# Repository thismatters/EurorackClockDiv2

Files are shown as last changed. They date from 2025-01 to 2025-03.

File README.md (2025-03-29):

# Clock Divider (type 2)

```
      ----  ----  ----  ----  ----  ----  ----  ----  ----
IN    |  |  |  |  |  |  |  |  |  |  |  |  |  |  |  |  |  |
    ---  ----  ----  ----  ----  ----  ----  ----  ----  ---
      ----              ----              ----
OUT   |  |              |  |              |  |
n=3 ---  ----------------  ----------------  ---------------
```

This clock divider takes a regular clock signal and generates one pulse every `n` input steps. A knob allows you choose `n` between 1 and 10. Combine this with the [binary clock divider](https://www.github.com/thismatters/EurorackClockDiv/) in my series to generate many permutations on a clock signal.

The circuit here is based on the [Yusynth Clock Divider](https://yusynth.net/Modular/EN/DIVIDER/index.html) with minor tweaks to make it more Eurorack friendly. The changes I've made are thus:
* Selected resistors appropriate for +/-12V rails,
* Added polarity protection so that a backward power header doesn't fry anything (twin series schotty diodes: BAT54SL),
* Full surface mount design,
* More step options!

The Yusynth page is a treasure trove of information about this circuit that I am too amateur to claim as my own; please read that outstanding page before using this circuit. The page provides many details and other implementations of this circuit that you may find suitable.

The KiCAD project here uses the library/footprints [found in my companion repo](https://github.com/thismatters/EurorackKiCAD).

## Width

10hp on a 1u rack (Intellijel).

## Inputs

Jacks:
- Clock input*
- Reset gate

Knobs:
- 10 position switch for choosing the frequency of gate outputs

\* Note that this module requires a fairly clean input clock signal.

## Outputs

Gate output. LED indicator.

## Vendors

There are part numbers in the [BOM](clkdiv2.csv) for many of the parts (not for basic passives though) at the following vendors:

* [Mouser](https://www.mouser.com): Needs no introduction. Get your ICs from here (or [digikey](https://www.digikey.com)).
* [Tayda Electronics](https://www.taydaelectronics.com/): Good supplier for passive components; audio jacks, and potentiometers. Their audio jacks are slightly smaller than the thonkiconn from thonk.
* [Love My Switches](https://lovemyswitches.com/): Has [really good knobs](https://lovemyswitches.com/anodized-aluminum-knob-the-lo-fi-1-4-smooth-shaft-12-5mm-od/) to go on those potentiometers!
* [OSHPark](https://oshpark.com/): Fast and (relatively) cheap PCB manufacturer. [V0a works great!](https://oshpark.com/shared_projects/LyyWQIPF)

## Changelog

### V0a (Same solder paste stencil as V0 will work here)
- [x] Fixed wrong schematic symbol for dual transistor package (Q3 pinout didn't match the BCM847.)
- [x] Fixed LED footprint to correct side of the board
- [x] Fixed D9 screenprint overlap

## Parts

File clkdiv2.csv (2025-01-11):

# | Reference | Qty | Value | Footprint | DNP | Vendor | PartNum
1 | C1, C2 | 2 | 22u 50V | Capacitor_THT:CP_Radial_D5.0mm_P2.50mm
2 | C3 | 1 | 100n | Capacitor_SMD:C_0805_2012Metric
3 | C4 | 1 | 47n box | Capacitor_THT:C_Rect_L7.2mm_W2.5mm_P5.00mm_FKS2_FKP2_MKS2_MKP2
4 | D1, D2 | 2 | BAT54S | Package_TO_SOT_SMD:SOT-23 |  | Mouser | 863-BAT54SLT1G
5 | D3, D4, D5, D6, D7, D8 | 6 | 1N4148 | Diode_SMD:D_SOD-323_HandSoldering
6 | D9 | 1 | Zener 5.1V | Diode_SMD:D_MiniMELF
7 | D10 | 1 | LED_GREEN | LED_THT:LED_D3.0mm
8 | J1 | 1 | Conn_02x05_Odd_Even | Eurorack:PinHeader_2x05_P2.54mm_Vertical |  | Tayda | A-2939
9 | J2, J3, J4 | 3 | AudioJack2_SwitchT | Eurorack:AudioJack2_Tayda_A-2566 |  | Tayda | A-2566
10 | J5, J7, J9 | 3 | Conn_01x03_Socket | Connector_PinSocket_2.54mm:PinSocket_1x03_P2.54mm_Vertical
11 | J6, J8, J10 | 3 | Conn_01x03_Pin | Connector_PinHeader_2.54mm:PinHeader_1x03_P2.54mm_Vertical
12 | Q1, Q2, Q3 | 3 | BCM847 | Package_SO:TSOP-6_1.65x3.05mm_P0.95mm |  | Mouser | 771-BCM847DS135
13 | R1, R2, R20 | 3 | 10 | Resistor_SMD:R_0805_2012Metric
14 | R3, R9 | 2 | 1M | Resistor_SMD:R_0805_2012Metric
15 | R4 | 1 | 1.2M | Resistor_SMD:R_0805_2012Metric
16 | R5, R6, R12, R14 | 4 | 22K | Resistor_SMD:R_0805_2012Metric
17 | R7 | 1 | 220 | Resistor_SMD:R_0805_2012Metric
18 | R8 | 1 | 100K | Resistor_SMD:R_0805_2012Metric
19 | R10 | 1 | 10K | Resistor_SMD:R_0805_2012Metric
20 | R11, R16 | 2 | 220K | Resistor_SMD:R_0805_2012Metric
21 | R13, R18, R19 | 3 | 1K | Resistor_SMD:R_0805_2012Metric
22 | R15 | 1 | 4.7K | Resistor_SMD:R_0805_2012Metric
23 | R17 | 1 | 120K | Resistor_SMD:R_0805_2012Metric
24 | SW1 | 1 | SW_Rotary12 | Eurorack:Switch_Rotary_NKK_MRK_112 |  | Mouser | 633-MRK112-BA
25 | U1 | 1 | 4017 | Package_SO:TSSOP-16_4.4x5mm_P0.65mm |  | Mouser | 595-CD4017BPWR

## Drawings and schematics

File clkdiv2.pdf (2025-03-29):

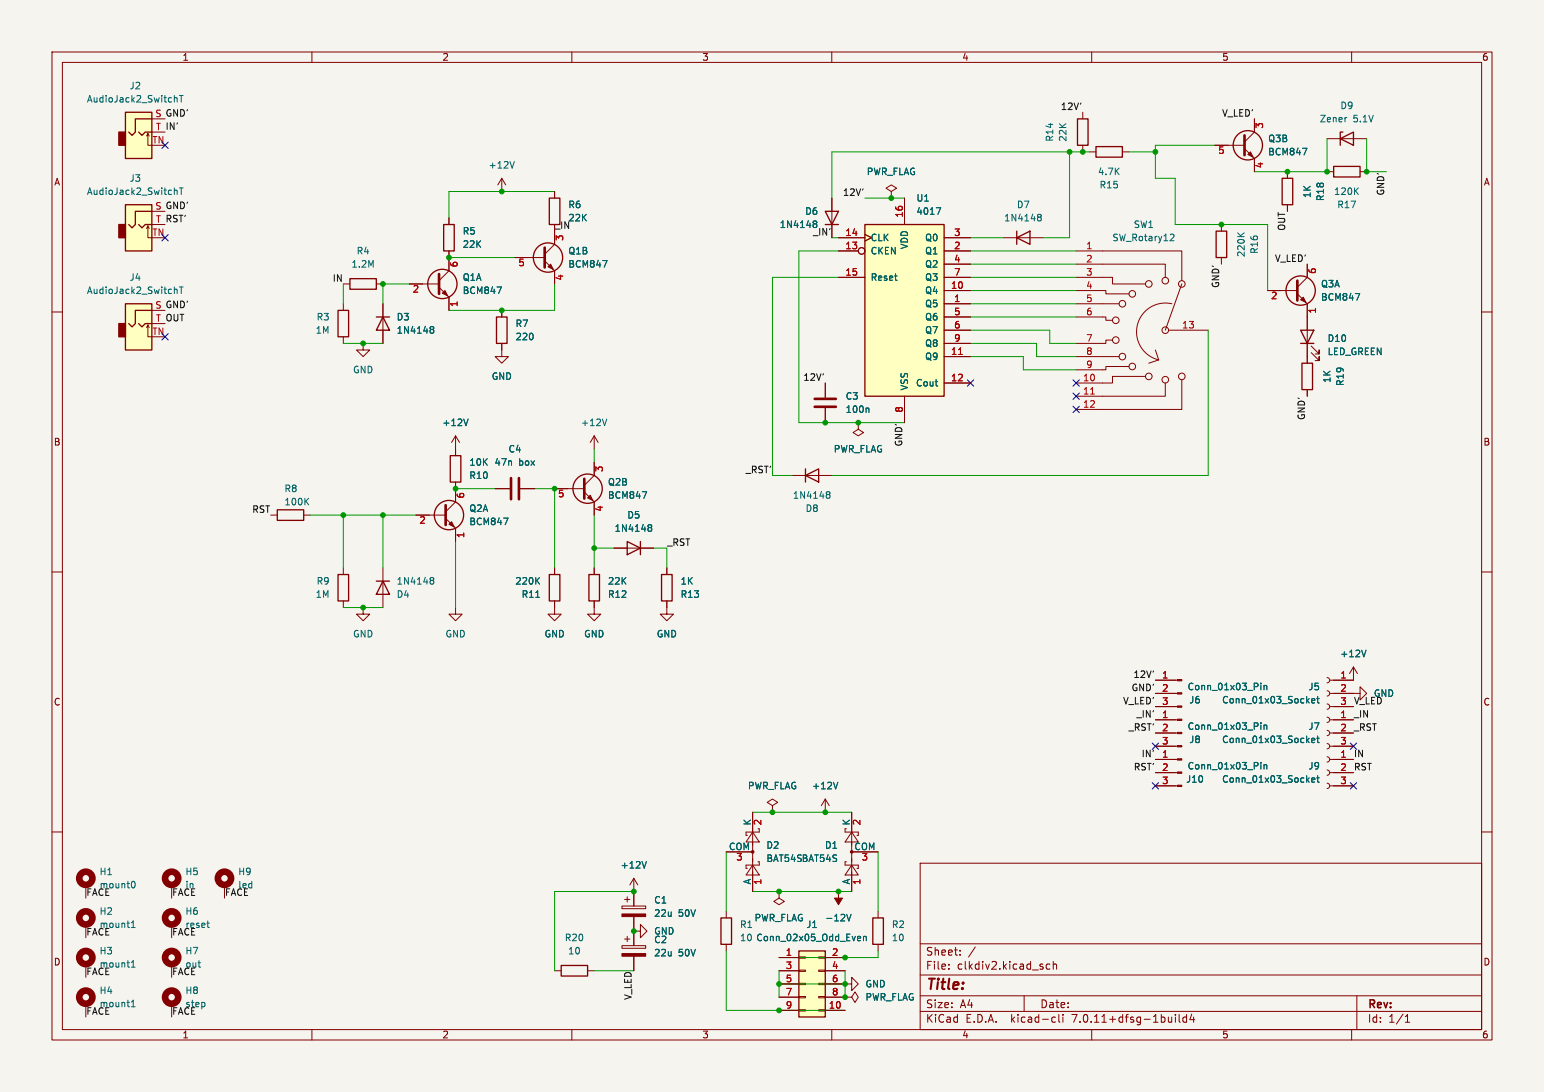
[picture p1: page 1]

Id: 1/1 Title: File: clkdiv2.kicad_sch Sheet: /

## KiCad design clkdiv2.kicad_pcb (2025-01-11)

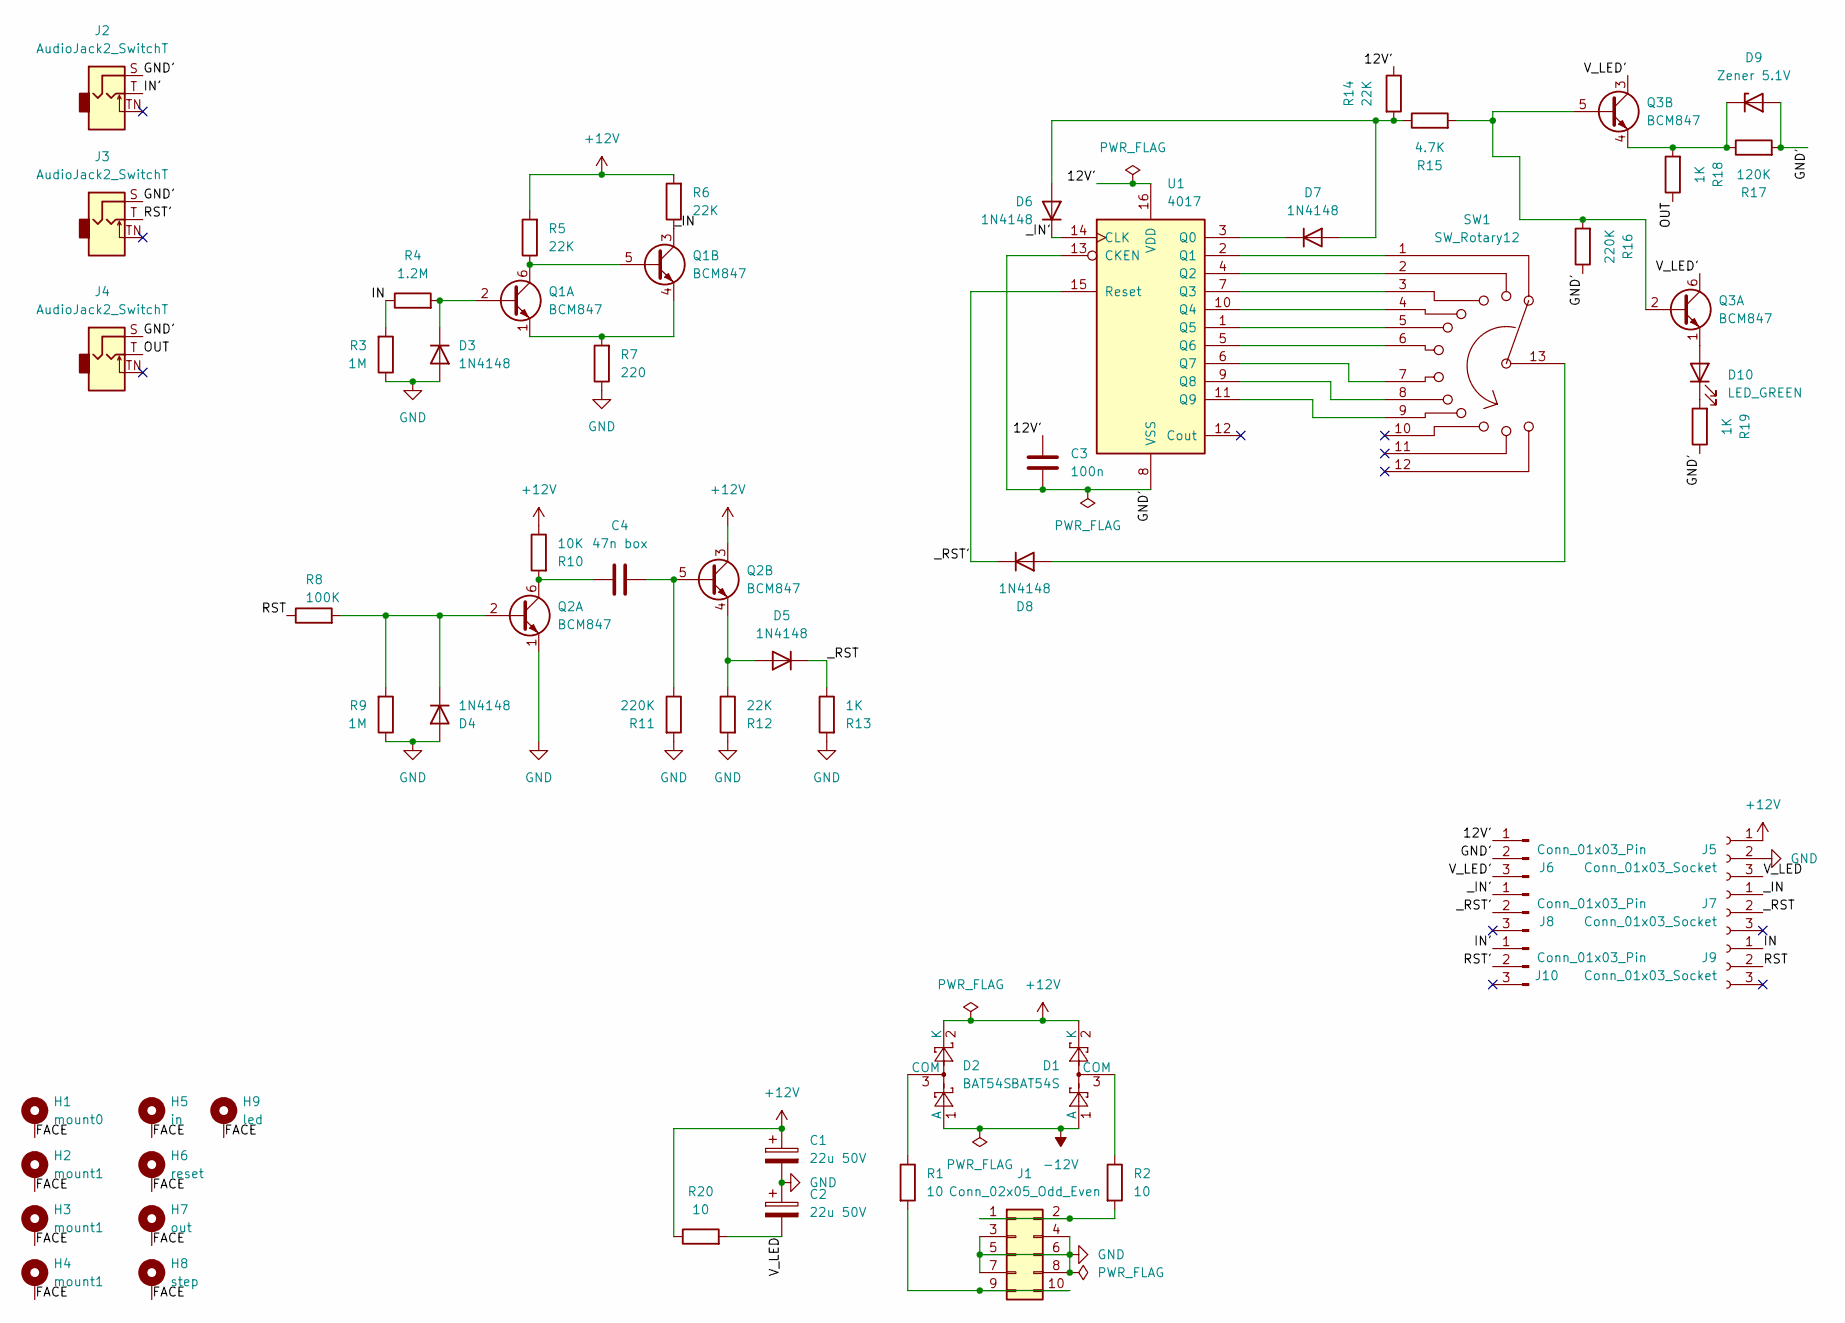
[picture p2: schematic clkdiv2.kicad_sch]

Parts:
C1, C2: 22u 50V; CP_Radial_D5.0mm_P2.50mm
C3: 100n; C_0805_2012Metric
C4: 47n box; C_Rect_L7.2mm_W2.5mm_P5.00mm_FKS2_FKP2_MKS2_MKP2
D1, D2: BAT54S; SOT-23; PartNum 863-BAT54SLT1G
D3, D4, D5, D6, D7, D8: 1N4148; D_SOD-323_HandSoldering
D9: Zener 5.1V; D_MiniMELF
D10: LED_GREEN; LED_D3.0mm
H1: mount0; Mech-MountingHole
H2, H3, H4: mount1; Mech-MountingHole
H5: in; Mech-AudioJack-Hole-Input-Clock
H6: reset; Mech-AudioJack-Hole-Input-Gate
H7: out; Mech-AudioJack-Hole-Output-Gate
H8: step; Mech-MRK-Hole
H9: led; Mech-LED-Hole-3mm-Bezel
J1: Conn_02x05_Odd_Even; PinHeader_2x05_P2.54mm_Vertical; PartNum A-2939
J2, J3, J4: AudioJack2_SwitchT; AudioJack2_Tayda_A-2566; PartNum A-2566
J5, J7, J9: Conn_01x03_Socket; PinSocket_1x03_P2.54mm_Vertical
J6, J8, J10: Conn_01x03_Pin; PinHeader_1x03_P2.54mm_Vertical
Q1, Q2, Q3: BCM847; TSOP-6_1.65x3.05mm_P0.95mm; PartNum 771-BCM847DS135
R1, R2, R20: 10; R_0805_2012Metric
R3, R9: 1M; R_0805_2012Metric
R4: 1.2M; R_0805_2012Metric
R5, R6, R12, R14: 22K; R_0805_2012Metric
R7: 220; R_0805_2012Metric
R8: 100K; R_0805_2012Metric
R10: 10K; R_0805_2012Metric
R11, R16: 220K; R_0805_2012Metric
R13, R18, R19: 1K; R_0805_2012Metric
R15: 4.7K; R_0805_2012Metric
R17: 120K; R_0805_2012Metric
SW1: SW_Rotary12; Switch_Rotary_NKK_MRK_112; PartNum 633-MRK112-BA
U1: 4017; TSSOP-16_4.4x5mm_P0.65mm; PartNum 595-CD4017BPWR

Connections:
+12V: C1.1, D1.2 (K), D2.2 (K), J5.1, Q2.3 (C2), R5.2, R6.2, R10.1, R20.1
-12V: D1.1 (A), D2.1 (A)
/12V': C3.1, J6.1, R14.1, U1.16 (VDD)
/FACE: H1.1, H2.1, H3.1, H4.1, H5.1, H6.1, H7.1, H8.1, H9.1
/GND': C3.2, D9.2 (A), J2.S, J3.S, J4.S, J6.2, R16.1, R17.2, R19.1, U1.8 (VSS), U1.13 (CKEN)
/IN: J9.1, R3.2, R4.1
/IN': J2.T, J10.1
/OUT: J4.T, R18.1
/RST: J9.2, R8.1
/RST': J3.T, J10.2
/V_LED: C2.2, J5.3, R20.2
/V_LED': J6.3, Q3.3 (C2), Q3.6 (C1)
/_IN: J7.1, Q1.3 (C2), R6.1
/_IN': D6.1 (K), J8.1, U1.14 (CLK)
/_RST: D5.1 (K), J7.2, R13.1
/_RST': D8.1 (K), J8.2, U1.15 (Reset)
GND: C1.2, C2.1, D3.2 (A), D4.2 (A), J1.3, J1.4, J1.5, J1.6, J1.7, J1.8, J5.2, Q2.1 (E1), R3.1, R7.1, R9.1, R11.2, R12.2, R13.2
unnamed: D1.3 (COM), R2.1
unnamed: D2.3 (COM), R1.1
unnamed: D3.1 (K), Q1.2 (B1), R4.2
unnamed: D4.1 (K), Q2.2 (B1), R8.2, R9.2
unnamed: D5.2 (A), Q2.4 (E2), R12.1
unnamed: D6.2 (A), D7.2 (A), R14.2, R15.1
unnamed: D7.1 (K), U1.3 (Q0)
unnamed: D8.2 (A), SW1.13
unnamed: D9.1 (K), Q3.4 (E2), R17.1, R18.2
unnamed: D10.2 (A), Q3.1 (E1)
unnamed: D10.1 (K), R19.2
unnamed: J1.1, J1.2, R2.2
unnamed: J1.9, J1.10, R1.2
unnamed: Q1.5 (B2), Q1.6 (C1), R5.1
unnamed: Q1.1 (E1), Q1.4 (E2), R7.2
unnamed: C4.1, Q2.6 (C1), R10.2
unnamed: C4.2, Q2.5 (B2), R11.1
unnamed: Q3.2 (B1), Q3.5 (B2), R15.2, R16.2
unnamed: SW1.1, U1.2 (Q1)
unnamed: SW1.2, U1.4 (Q2)
unnamed: SW1.3, U1.7 (Q3)
unnamed: SW1.4, U1.10 (Q4)
unnamed: SW1.5, U1.1 (Q5)
unnamed: SW1.6, U1.5 (Q6)
unnamed: SW1.7, U1.6 (Q7)
unnamed: SW1.8, U1.9 (Q8)
unnamed: SW1.9, U1.11 (Q9)

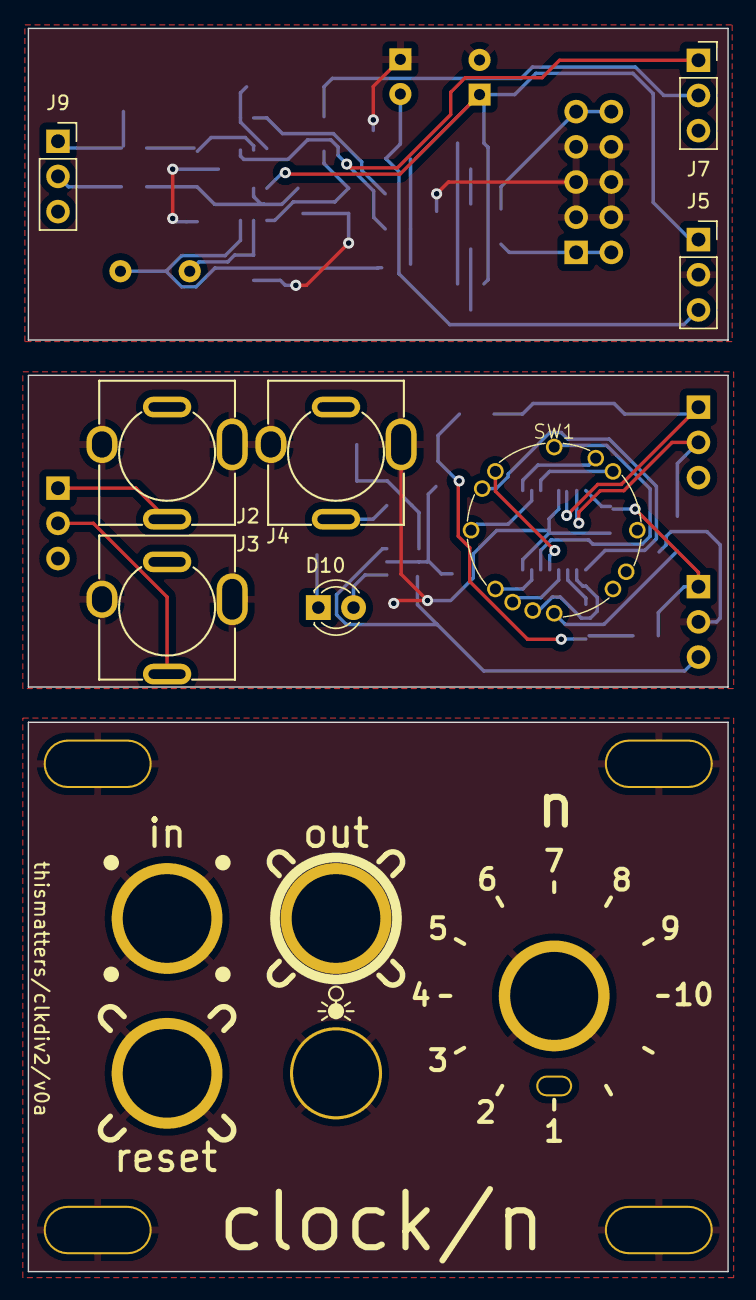
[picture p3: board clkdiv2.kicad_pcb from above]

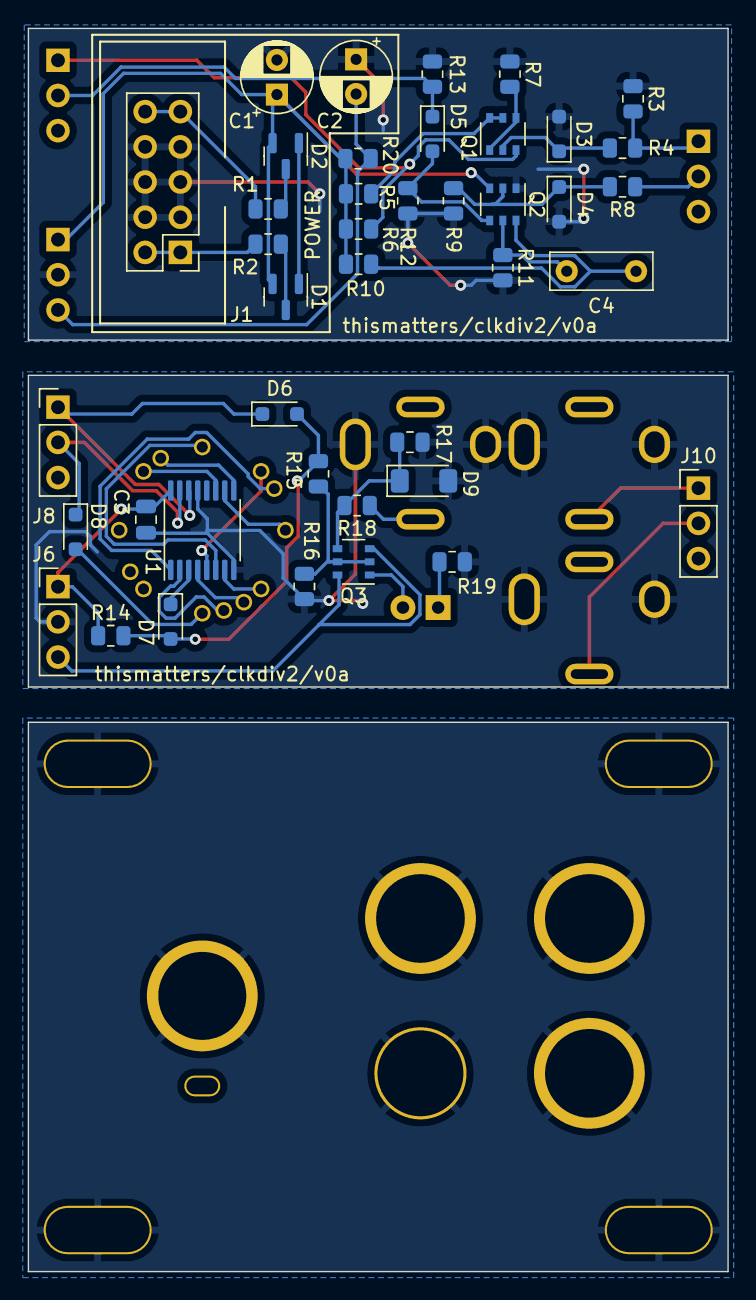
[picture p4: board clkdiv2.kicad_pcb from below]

Board: 2 copper layers, 50.5 x 89.7 mm, 58 parts (41 on the bottom side), 44 nets.

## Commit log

2024-11-30 initial commit, prebreadboard
    [clkdiv2.kicad_pcb, clkdiv2.kicad_sch]
2024-12-06 pcb ready for v0 manu
    [clkdiv2.csv, clkdiv2.kicad_pcb, clkdiv2.kicad_sch]
2025-01-11 pcb ready for v0a manu
    [clkdiv2.csv, clkdiv2.kicad_pcb, clkdiv2.kicad_sch]
